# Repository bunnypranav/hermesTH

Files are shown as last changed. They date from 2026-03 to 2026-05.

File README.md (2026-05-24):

# Bunny's Hermes-TH
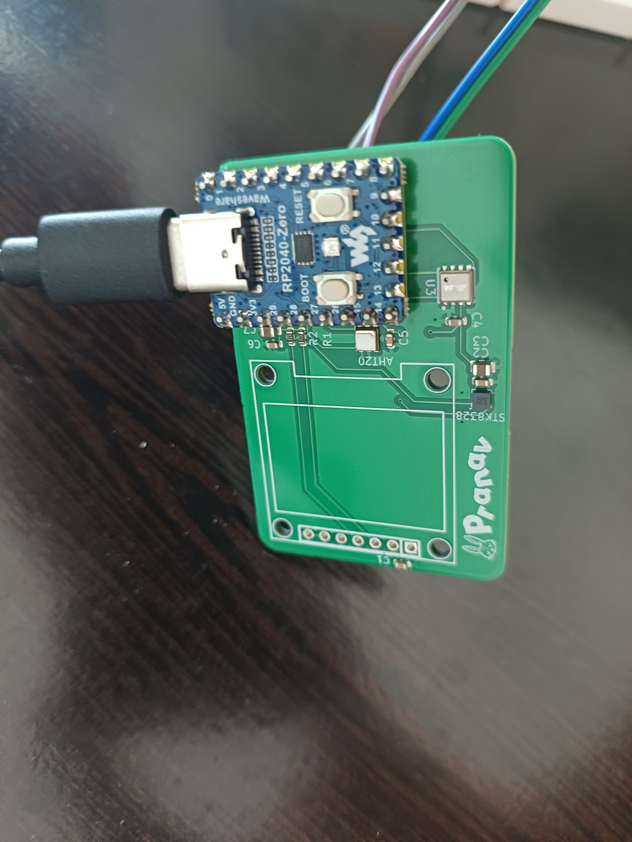
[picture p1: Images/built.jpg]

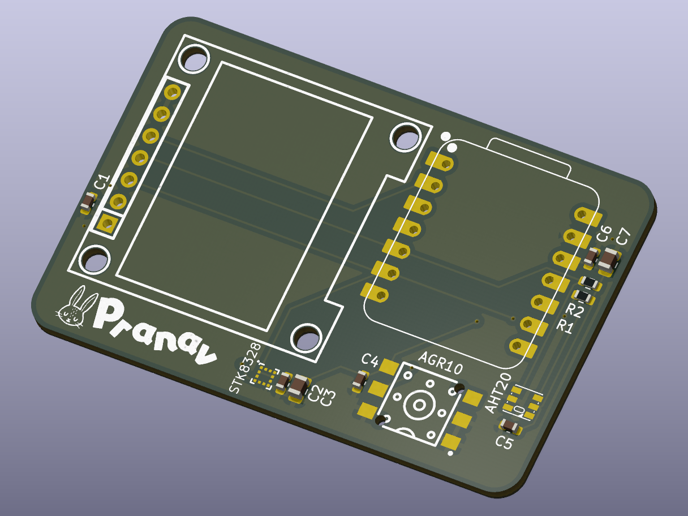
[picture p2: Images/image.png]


Hermes-TH is a small PCB that combines a temperature and humidity sensor, pressure sensor, and accelerometer, specifically the AHT20-F, AGR10, STK8328-C with a tiny OLED display, all controlled by a XIAO RP2040. The idea was to make a simple I2C-based board that reads environmental data that actually matters in my life, namely temperature, humidity, and pressure (unlike carbon monoxide for example), and displays it directly on a screen.

# Schematic
*Made in KiCad*

The XIAO RP2040 module handles everything. D4 and D5 are used for I2C (SCL and SDA), which are shared by the AHT20, OLED, and the accelerometer. The accelerometer is an analog device and read through the ADC pins of the RP2040, specifically A0. All other components are simply controlled through the I2C bus and everything is powered with 3.3V from the RP2040. The OLED is a 128x64 pixel display, which is more than enough for displaying all statistics.

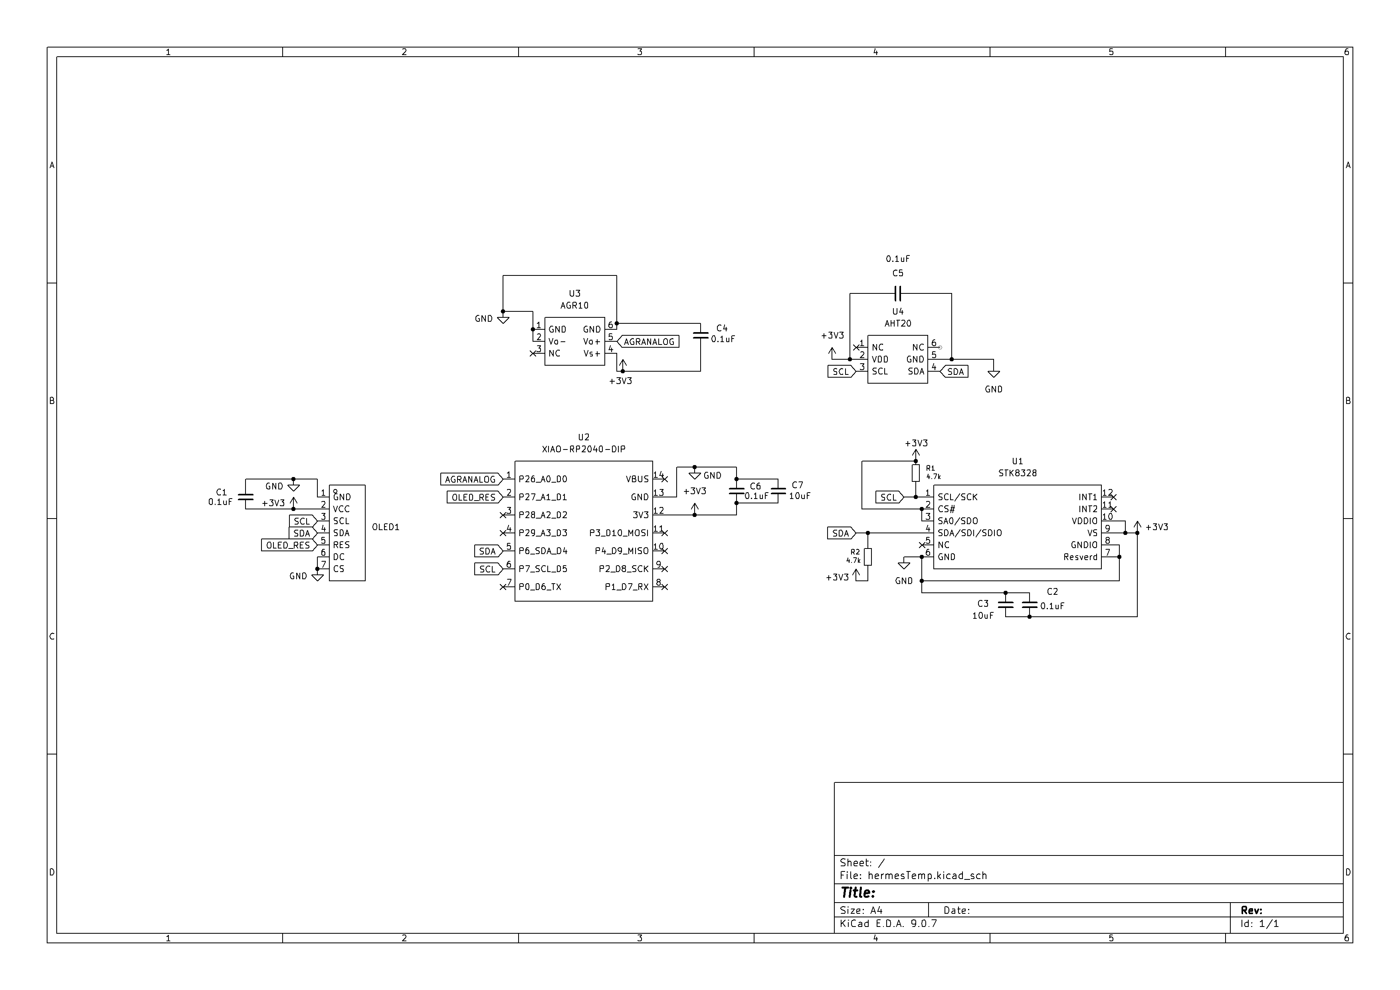
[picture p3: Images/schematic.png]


# PCB
*Made in KiCad*
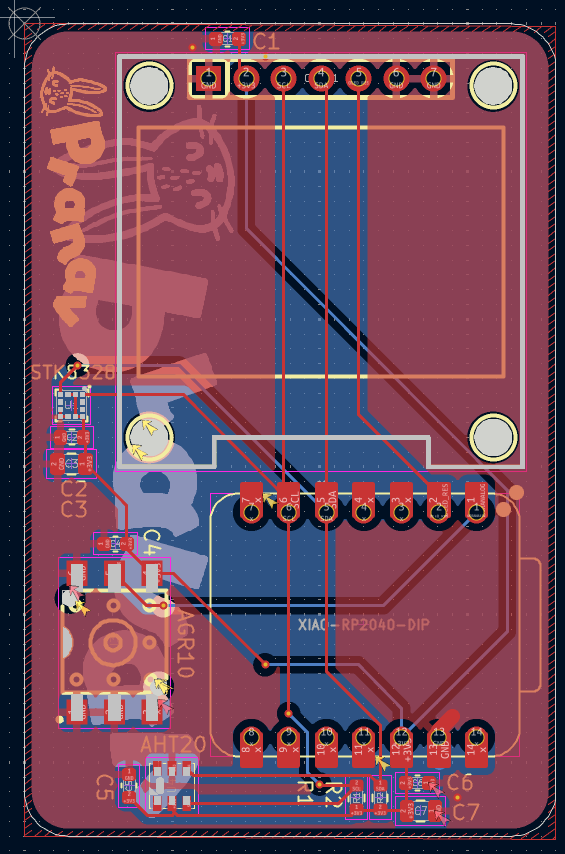
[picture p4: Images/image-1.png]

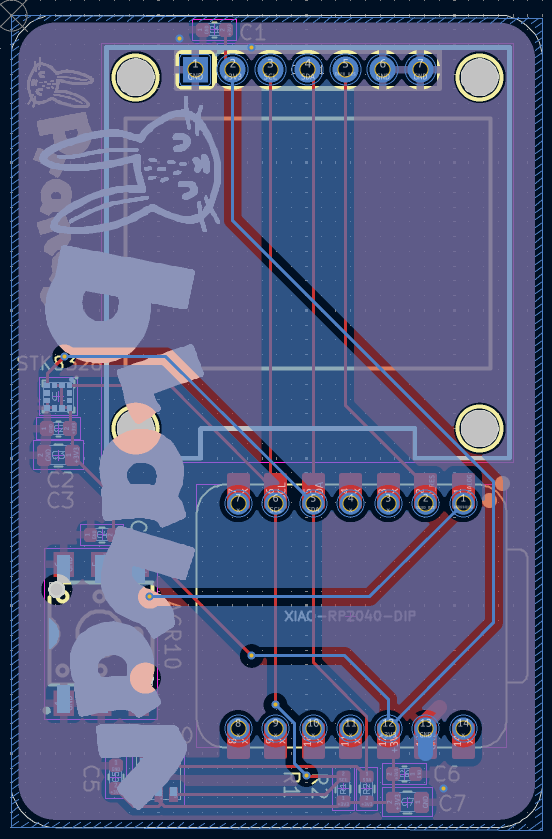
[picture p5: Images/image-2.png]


# BOM
* JLC PCBA: USD$37.5 (includes cost of some components)
* OLED: USD$1.9
* XIAO RP2040: USD$6.7
* Robu.in Shipping: USD$0.53
* **Total: USD$46.63**

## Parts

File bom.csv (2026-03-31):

Name | Purpose | Quantity | Total Cost (USD) | Link | Distributor
XIAO RP2040 | Main MCU | 1 | 6.70 | https://robu.in/product/seeed-studio-xiao-rp2040-v1-0/ | Robu
OLED Screen | Displaying the stats collected | 1 | 1.90 | https://robu.in/product/0-96-oled-display-module-spi-i2c-128x64-7-pin-blue/ | Robu
JLC PCB and Assemby | PCBA of SMD sensors, caps and resistors | 1 | 37.50 | https://jlcpcb.com/ | JLCPCB

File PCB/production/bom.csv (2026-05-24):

Designator | Footprint | Quantity | Value | LCSC Part #
C1, C2, C4, C5, C6 | 0603 | 5 | 0.1uF
C3, C7 | 0805 | 2 | 10uF
OLED1 | OLED-TH_HS96L01W4S03 | 1 | ~
R1, R2 | 0603 | 2 | 4.7k
U1 | VLGA-12_L2.0-W2.0-P0.50-BL | 1 | STK8328
U2 | MODULE_RP2040-ZERO | 1 | RP2040-ZERO
U3 | LGA-8_L3.8-W3.6-P0.90-TL_WF183D | 1 | ~
U4 | SENSOR-SMD-6_AHT20 | 1 | AHT20

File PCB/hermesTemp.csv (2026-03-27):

Reference | Qty | Value | DNP | Exclude from BOM | Exclude from Board | Footprint | Datasheet
C1,C2,C7 | 3 | 0.1uF |  |  |  | Capacitor_SMD:C_0603_1608Metric | ~
C3,C4,C5 | 3 | 1uF |  |  |  | Capacitor_SMD:C_0603_1608Metric | ~
C6,C9 | 2 | 4.7uF |  |  |  | Capacitor_SMD:C_0603_1608Metric | ~
C8 | 1 | 2.2uF |  |  |  | Capacitor_SMD:C_0603_1608Metric | ~
C10 | 1 | 10uF |  |  |  | Capacitor_SMD:C_0603_1608Metric | ~
R1,R2 | 2 | 4.7k |  |  |  | Resistor_SMD:R_0603_1608Metric | ~
R3 | 1 | 1M |  |  |  | Resistor_SMD:R_0603_1608Metric | ~
R4,R5 | 2 | 10k |  |  |  | Resistor_SMD:R_0603_1608Metric | ~
U1 | 1 | STM32F103C8T6 |  |  |  | hermesExtraFoot:STM32F103C8T6 | https://item.szlcsc.com/datasheet/LCKFB-DKX-STM32F103C8T6/24005615.html
U2 | 1 | AHT20-F |  |  |  | hermesExtraFoot:SENSOR-SMD-6_AHT20 | https://item.szlcsc.com/datasheet/AHT20-F/3517691.html
U3 | 1 | N069-9616TSWPG02-H14 |  |  |  | hermesExtraFoot:LCD-SMD_N069-9616TSWPG02-H14 | https://item.szlcsc.com/datasheet/N069-9616TSWPG02-H14/5717754.html

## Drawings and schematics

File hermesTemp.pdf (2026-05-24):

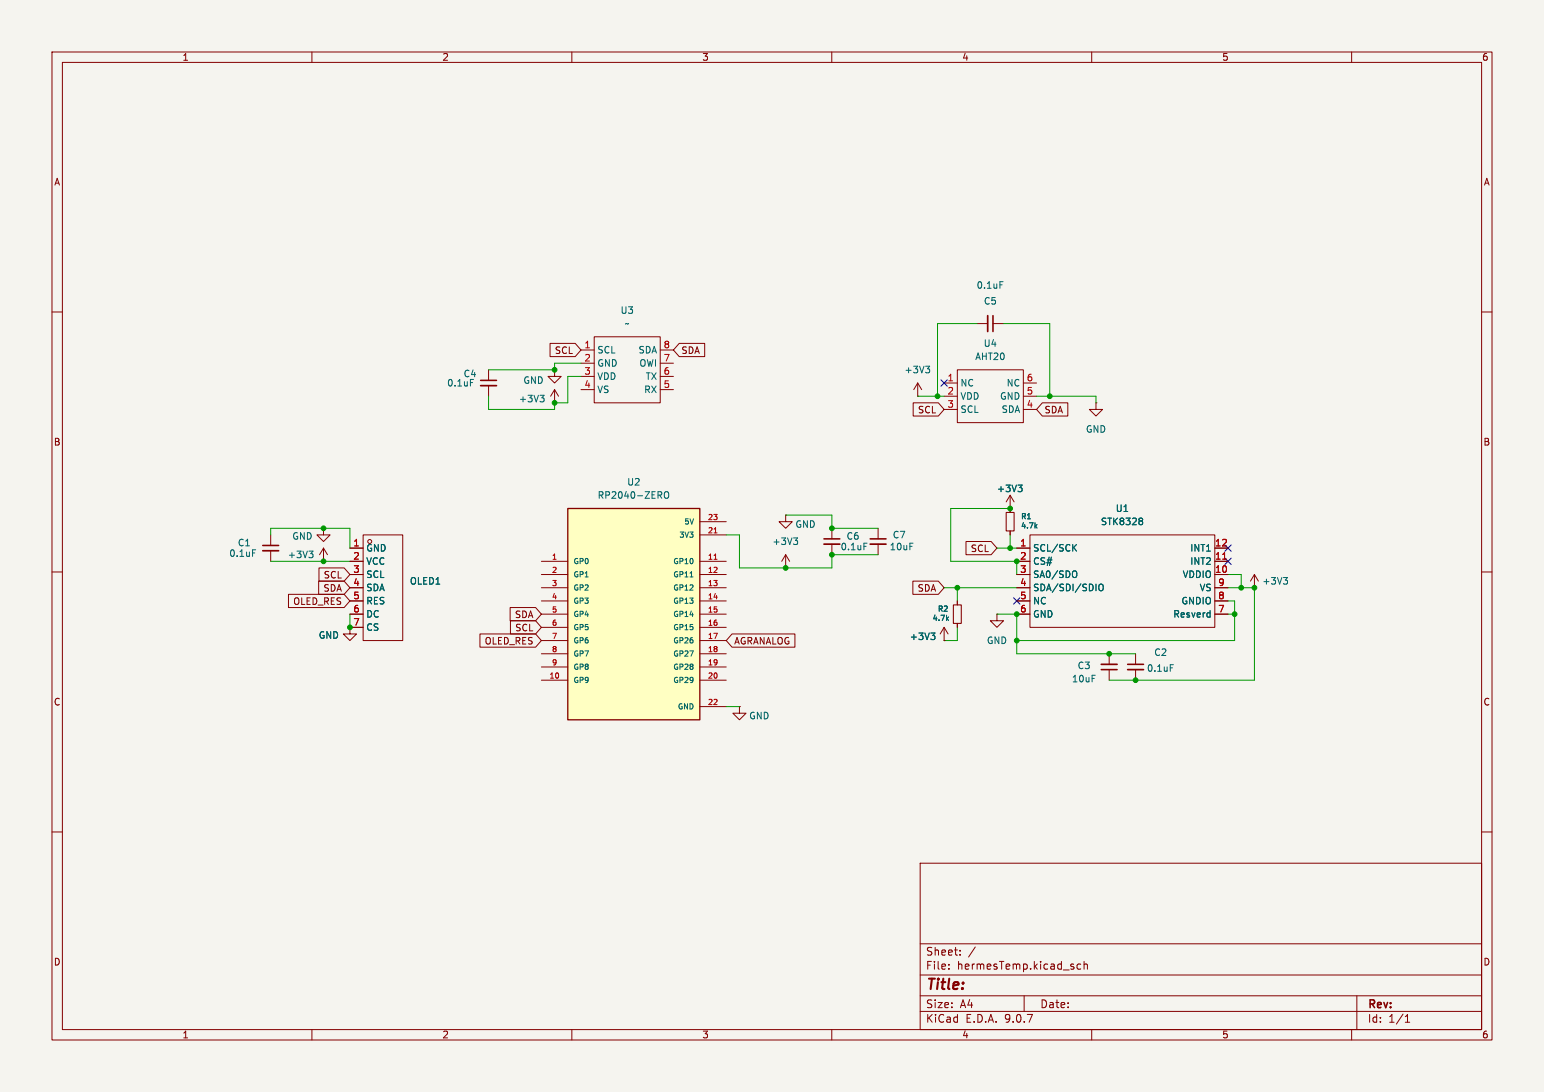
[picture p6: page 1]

Id: 1/1 Title: File: hermesTemp.kicad_sch Sheet: / C7

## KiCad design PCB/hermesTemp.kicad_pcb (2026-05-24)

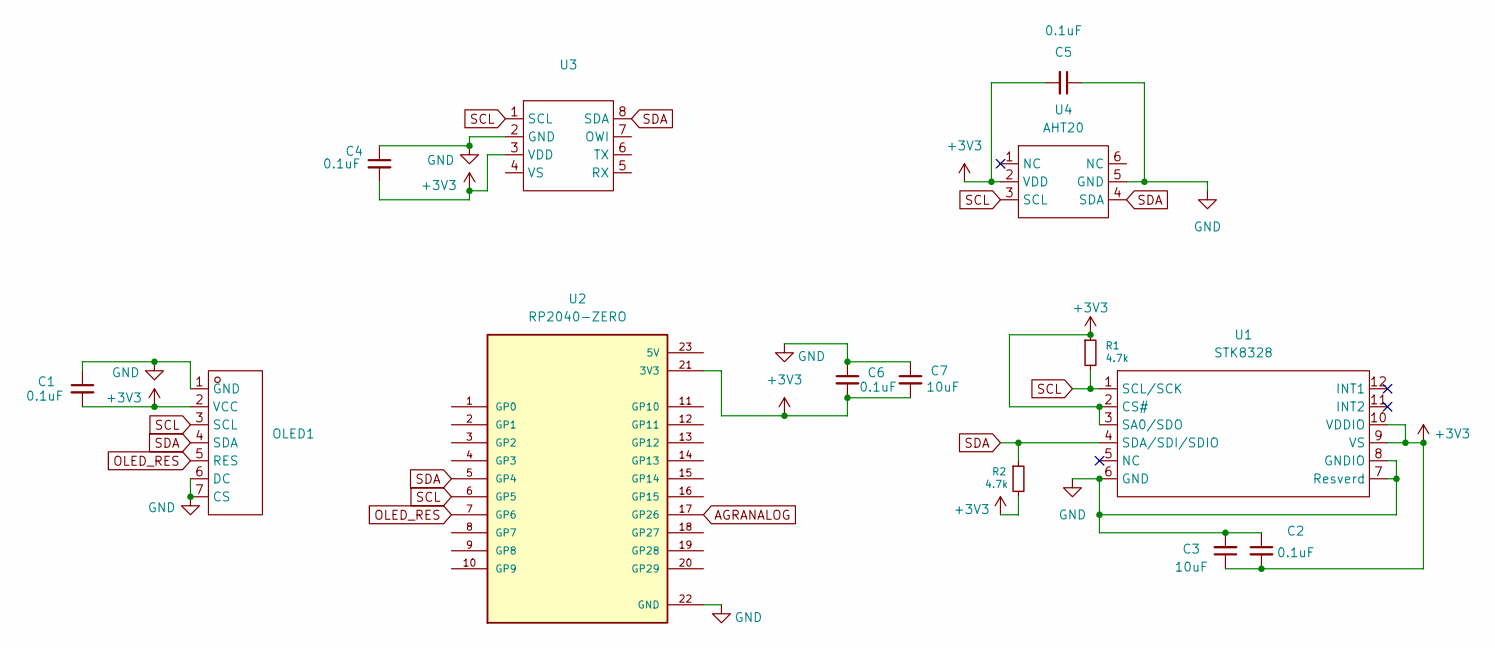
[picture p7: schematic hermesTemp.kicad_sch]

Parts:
C1, C2, C4, C5, C6: 0.1uF; C_0603_1608Metric
C3, C7: 10uF; C_0805_2012Metric
OLED1: OLED-TH_HS96L01W4S03; Manufacturer Part HS96L01W4S03; LCSC Part Name 0.96寸 白光 128x64像素分辨率
R1, R2: 4.7k; R_0603_1608Metric
U1: STK8328; VLGA-12_L2.0-W2.0-P0.50-BL; Manufacturer Part STK8328-C; LCSC Part Name 数字输出三轴MEMS加速度计
U2: RP2040-ZERO; MODULE_RP2040-ZERO; PARTREV NA
U3: LGA-8_L3.8-W3.6-P0.90-TL_WF183D; Manufacturer Part WF183DE 15BA L8N T&R; LCSC Part Name 数字压力传感器 量程：0-1500kpa 工作电压：2.4~5.5V 通信接口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
U4: AHT20; SENSOR-SMD-6_AHT20; Manufacturer Part AHT20-F; LCSC Part Name 温湿度传感器

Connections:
+3V3: C1.2, C2.2, C3.1, C4.2, C5.2, C6.2, C7.2, OLED1.2 (VCC), R1.1, R2.2, U1.2 (CS#), U1.3 (SA0/SDO), U1.9 (VS), U1.10 (VDDIO), U2.21 (3V3), U3.3 (VDD), U4.2 (VDD)
AGRANALOG: U2.17 (GP26)
GND: C1.1, C2.1, C3.2, C4.1, C5.1, C6.1, C7.1, OLED1.1 (GND), OLED1.6 (DC), OLED1.7 (CS), U1.6 (GND), U1.7 (Resverd), U1.8 (GNDIO), U2.22 (GND), U3.2 (GND), U4.5 (GND)
OLED_RES: OLED1.5 (RES), U2.7 (GP6)
SCL: OLED1.3 (SCL), R1.2, U1.1 (SCL/SCK), U2.6 (GP5), U3.1 (SCL), U4.3 (SCL)
SDA: OLED1.4 (SDA), R2.1, U1.4 (SDA/SDI/SDIO), U2.5 (GP4), U3.8 (SDA), U4.4 (SDA)

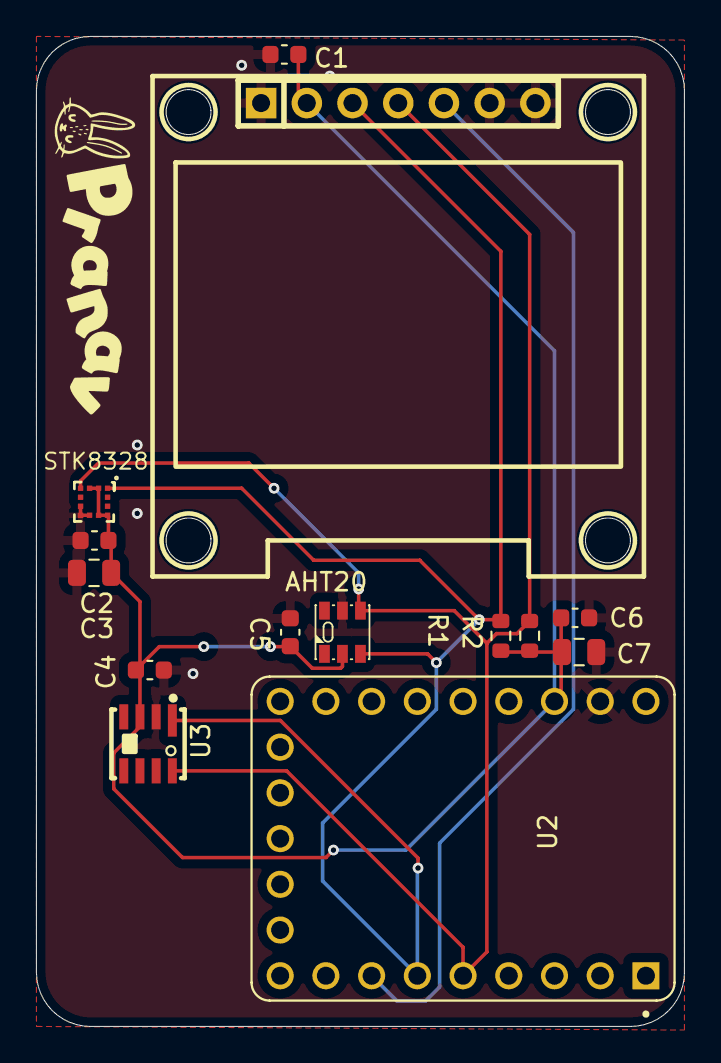
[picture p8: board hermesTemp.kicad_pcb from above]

Board: 2 copper layers, 36.0 x 55.0 mm, 15 parts (1 on the bottom side), 5 nets.

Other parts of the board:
P2: LOGO

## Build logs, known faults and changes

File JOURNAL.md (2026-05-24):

<!--
  This journal is auto generated by Stasis.
-->

# 5/24/2026 10 AM - Build done!

_Time spent: 1.25h_

Finally finished the build of the project! The screen correctly displays the values from the sensors, and regularly updates them. 

I have to say, it wasn't without any struggles. Biggest problem was that the screen that I put in the PCB uses SPI, but I wired it up for I2C. Tiny misprints making our lives harder, *sigh!* So now the only way I had was to use another I2C screen I had lying around, and connect it to the breadboard. Changing or ordering another PCB is of no use, I don't have the US$40-ish to pay to JLC along with another US$10 for customs. Anyways, this was a hobby prototype, and it works perfectly relative to prototypes. Enjoy the photos!

built1

built2




# 3/31/2026 4 PM - Rework design based on review feedback

_Time spent: 4.5h_

This update mostly happened because of the feedback I got on the last review. The main issue was that the project wasn't complex for Tier 2, and was too expensive for Tier 1. Additionally, the reviewer pointed out some key cost-cutting measures, which I did feel were really doable. So I had to rethink the direction a bit instead of just tweaking small things.

Earlier, it was mostly just a display and one sensor. Based on the suggestion, I added two more sensors;  the STK8328 accelerometer, and the AGR10 pressure sensor. It also made me deal with two types of interfaces, namely I2C and analog, which added to the complexity in a meaningful way.



Another suggestion was about my PCBA choice and improving how parts were sourced. I made the OLED setup simpler by using a module instead of bare SMD ribbon cable, which got me rid of the complex charge pump system and related.  The feedback about the STM32 and PCBA cost also made me rethink the microcontroller choice. I switched to the XIAO RP2040, sourced through Robu and will be later soldered by me. Not getting the OLED and MCU through PCBA will reduce the cost, since PCBA will buy and solder two of each component, something that is not cost-effective at all.



I also updated the firmware to work with all the new components, and it now used CircuitPython. The pressure part is a bit rough since it's based on a simple and uncalibrated conversion for now.



Overall, I think I addressed the feedback properly. The project is now clearly more complex than before, while also being more practical and cheaper to build, relative to the components used.





# 3/25/2026 11 AM - PCB Routing and firmware

_Time spent: 3.25h_

PCB routing was actually pretty easy. There were only 3 main components, the MCU (STM32), the OLED display, and the AHT20. The rest are pull up resistors, and a whole array of decoupling capacitors. Since this is not my very first time using them, I am aware that they should be placed as close as possible to the pins. Fortunately, I am getting this as a PCBA, so size is not a problem. I went with 0605 size, so I could fit them all fairly easily around the pins. A dual ground plane helped for routing, noise, as well as aesthetics.  Regarding the firmware, I just wanted a proof of concept, since this is my first time using an STM32, and therfore I know next to nothing about it. Using my basic knowledge of MicroPython, and some help from an AI, I created the most basic firmware. This is subject to most amount of change, for afformentioned reasons. Adding some ~~propoganda~~ branding of my own, and the PCB routing along with the full design is finally done!

Cherish some PCB images below, thanks for taking a look at my design!












# 3/25/2026 8 AM - Schematic

_Time spent: 2.5h_

After less time than I expected, but more components than I expected, I have finished the schematic! I thought it would just be connecting components together, but there were a lot of small details.

The STM32 module itself was straightforward since most pins were already labelled clearly; although my first time needing pull up resistors, cause I previously only worked with Picos (they have this in-built). The AHT20 sensor was also relatively simple.

The OLED display was the behemoth of confusion. It had a lot extra pins that I didn't understand, especially the "charge pump" ones: C1P, C1N, C2P, and C2N. I had to refer to the datasheet multiple times (and other sources to look up sample wiring) and still wasn't fully confident about whether I understood everything correctly. Adding the numerous required capacitors and the resistor made the schematic look even more complicated.

The decoupling capacitors were also frustrating to draw up. Every component seemed to need more than one! I ended up following general guidelines, like adding a mix of small and big ones.

I had to go through this big mess multiple times, checking connections and making sure nothing was left; eventually everything seemed to be connected properly.














# 3/24/2026 12 PM - Researching parts and finalizing BOM

_Time spent: 3h_

At the start of this project, I wanted to use the bare RP2040 SMD version. It is used in a lot of projects and I was fairly familiar with RPI Picos. Once I actually started researching how to use the bare chip though, I realised that it needed a lot of extra components like flash memory, crystal oscillator, power stuff, and a bunch of capacitors. This was beyond the Hermes' simple I2C board.

Therefore, I switched to the STM32 module (STM32F103C8T6, specifically, since that is available in JLC PCB fab). For the sensor, I chose the AHT20 because it was popular and cheap. The OLED display choice was a lot more confusing. I wanted this to be a fully assembled PCB, since that is cheaper than ordering components from local sellers. So I deeply searched through JLC's parts library, keeping in mind economic PCBA and trying my best to avoid exteneded components to save on cost. That particulary was a very big problem for the OLED, since it had too many variables like having I2C, being eligible for economic PCBA, and not having assembly difficulty of "high" (this was a new one for me, but very important cause each such component adds more than 3 USD to it's assembly). I also had to add a whole array of decoupling caps and resistors for making these work, something I will ellaborate in the next journal.

I finally settled on these for my main components:
https://jlcpcb.com/partdetail/Aosong_Guangzhou_Elec-AHT20F/C3012622
https://jlcpcb.com/partdetail/Newvisio-N069_9616TSWPG02H14/C5123561
https://jlcpcb.com/partdetail/LCSCboards-LCKFB_DKXSTM32F103C8T6/C22396880











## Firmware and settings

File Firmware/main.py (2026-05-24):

import time
import struct
import framebuf
from machine import I2C, Pin

i2c = I2C(0, sda=Pin(4), scl=Pin(5), freq=400_000)


def i2c_write(addr, data):
    i2c.writeto(addr, data)


def i2c_read(addr, n):
    return i2c.readfrom(addr, n)


def i2c_write_reg(addr, reg, val):
    i2c.writeto(addr, bytes([reg, val]))


def i2c_read_reg(addr, reg, n):
    i2c.writeto(addr, bytes([reg]))
    return i2c.readfrom(addr, n)


# STK8328-C
STK_ADDR = 0x1F
STK_REG_CHIP_ID = 0x00
STK_REG_XOUT1 = 0x02
STK_REG_RANGESEL = 0x0F
STK_REG_BWSEL = 0x10
STK_REG_POWMODE = 0x11
STK_REG_SWRST = 0x14

STK_RANGE_2G = 0x03
STK_RANGE_4G = 0x05
STK_RANGE_8G = 0x08
STK_RANGE_16G = 0x0C
STK_BW_125HZ = 0x0C

_STK_SENSITIVITY = {
    STK_RANGE_2G: 16384.0,
    STK_RANGE_4G: 8192.0,
    STK_RANGE_8G: 4096.0,
    STK_RANGE_16G: 2048.0,
}
_stk_range = STK_RANGE_8G


def stk_init():
    i2c_write_reg(STK_ADDR, STK_REG_SWRST, 0xB6)
    time.sleep_ms(10)
    chip_id = i2c_read_reg(STK_ADDR, STK_REG_CHIP_ID, 1)[0]
    if chip_id != 0x25:
        print("[STK8328] WARNING: chip_id 0x{:02X} (expected 0x25)".format(chip_id))
    else:
        print("[STK8328] chip_id OK: 0x{:02X}".format(chip_id))
    i2c_write_reg(STK_ADDR, STK_REG_POWMODE, 0x80)
    time.sleep_ms(2)
    i2c_write_reg(STK_ADDR, STK_REG_RANGESEL, _stk_range)
    i2c_write_reg(STK_ADDR, STK_REG_BWSEL, STK_BW_125HZ)
    i2c_write_reg(STK_ADDR, STK_REG_POWMODE, 0x00)
    time.sleep_ms(5)


def stk_read_accel():
    raw = i2c_read_reg(STK_ADDR, STK_REG_XOUT1, 6)

    def s16(lo, hi):
        v = (hi << 8) | lo
        return v - 0x10000 if v >= 0x8000 else v

    sens = _STK_SENSITIVITY[_stk_range]
    return (
        s16(raw[0], raw[1]) / sens,
        s16(raw[2], raw[3]) / sens,
        s16(raw[4], raw[5]) / sens,
    )


# WF183DE
WF_ADDR = 0x6D
WF_REG_CMD = 0x0A
WF_REG_PRES = 0x0B
WF_REG_TEMP = 0x0F
WF_REG_STS = 0x13
WF_CMD_TEMP = 0x04
WF_CMD_PRES = 0x06


def _wf_wait(timeout_ms=200):
    t = time.ticks_add(time.ticks_ms(), timeout_ms)
    while time.ticks_diff(t, time.ticks_ms()) > 0:
        try:
            i2c.writeto(WF_ADDR, bytes([WF_REG_STS]))
            if i2c.readfrom(WF_ADDR, 1)[0] & 0x01:
                return True
        except Exception:
            pass
        time.sleep_ms(5)
    return False


def wf_read_temp():
    i2c.writeto(WF_ADDR, bytes([WF_REG_CMD, WF_CMD_TEMP]))
    _wf_wait()
    i2c.writeto(WF_ADDR, bytes([WF_REG_TEMP]))
    raw = i2c.readfrom(WF_ADDR, 2)
    val = (raw[0] << 8) | raw[1]
    if val >= 0x8000:
        val -= 0x10000
    return val / 10.0


def wf_read_pressure():
    i2c.writeto(WF_ADDR, bytes([WF_REG_CMD, WF_CMD_PRES]))
    _wf_wait()
    i2c.writeto(WF_ADDR, bytes([WF_REG_PRES]))
    raw = i2c.readfrom(WF_ADDR, 4)
    val = (raw[0] << 24) | (raw[1] << 16) | (raw[2] << 8) | raw[3]
    return val / 1000.0


# OLED
OLED_ADDR = 0x3C
OLED_W = 128
OLED_H = 64

_OLED_INIT_CMDS = bytes(
    [
        0xAE,
        0xD5,
        0x80,
        0xA8,
        0x3F,
        0xD3,
        0x00,
        0x40,
        0x8D,
        0x14,
        0x20,
        0x00,
        0xA1,
        0xC8,
        0xDA,
        0x12,
        0x81,
        0xCF,
        0xD9,
        0xF1,
        0xDB,
        0x40,
        0xA4,
        0xA6,
        0xAF,
    ]
)

_oled_buf = bytearray(OLED_W * OLED_H // 8)
_oled_fb = framebuf.FrameBuffer(_oled_buf, OLED_W, OLED_H, framebuf.MONO_VLSB)
_oled_present = False


def _oled_cmds(data):
    for b in data:
        i2c.writeto(OLED_ADDR, bytes([0x00, b]))


def oled_init():
    global _oled_present

    if OLED_ADDR not in i2c.scan():
        print("[OLED]   not found on bus (0x{:02X})".format(OLED_ADDR))
        return False
    try:
        _oled_cmds(_OLED_INIT_CMDS)
        _oled_fb.fill(0)
        oled_show()
        _oled_present = True
        print("[OLED]   initialised (128x64, 4-pin no reset)")
        return True
    except Exception as e:
        print("[OLED]   init error:", e)
        return False


def oled_show():
    if not _oled_present:
        return
    _oled_cmds(bytes([0x21, 0, 127, 0x22, 0, 7]))
    chunk = 16
    for offset in range(0, len(_oled_buf), chunk):
        i2c.writeto(OLED_ADDR, b"\x40" + _oled_buf[offset : offset + chunk])


def oled_update(ax, ay, az, t_wf, pres):
    fb = _oled_fb
    fb.fill(0)

    fb.fill_rect(0, 0, 128, 12, 1)
    fb.text("HERMES SENSORS", 8, 2, 0)

    fb.text("STK8328", 4, 16, 1)
    fb.text("X: {:.2f} g".format(ax if ax is not None else 0), 4, 28, 1)
    fb.text("Y: {:.2f} g".format(ay if ay is not None else 0), 4, 40, 1)
    fb.text("Z: {:.2f} g".format(az if az is not None else 0), 4, 52, 1)
    fb.vline(82, 16, 48, 1)
    fb.text("WF183", 88, 16, 1)

    if t_wf is not None:
        fb.text("{:.1f}C".format(t_wf), 88, 32, 1)
    else:
        fb.text("T:N/A", 88, 32, 1)

    if pres is not None:
        fb.text("{:.1f}".format(pres), 88, 44, 1)
        fb.text("kPa", 88, 54, 1)
    else:
        fb.text("P:N/A", 88, 44, 1)

    oled_show()


# Main


def scan_bus():
    devices = i2c.scan()
    print("I2C scan:", [hex(d) for d in devices])


def main():
    print("=" * 50)
    print("  Hermes Sensor Board - MicroPython")
    print("=" * 50)

    time.sleep_ms(200)
    scan_bus()

    print("\nInitialising sensors...")
    stk_init()
    print("[WF183DE] ready")
    oled_init()

    print("\nStarting read loop. Press Ctrl-C to stop.\n")
    print(
        "{:>8} | {:>7} {:>7} {:>7} | {:>11} {:>9} | {:>10} {:>10}".format(
            "Time(s)", "Ax(g)", "Ay(g)", "Az(g)", "Temp_WF", "Pres(kPa)"
        )
    )
    print("-" * 85)

    t0 = time.ticks_ms()

    def fmt(v, w, d):
        return (
            "{:>{}.{}f}".format(v, w, d)
            if v is not None
            else "{:>{}s}".format("N/A", w)
        )

    while True:
        elapsed = time.ticks_diff(time.ticks_ms(), t0) / 1000.0

        try:
            ax, ay, az = stk_read_accel()
        except Exception as e:
            ax = ay = az = None
            print("[STK8328] read error:", e)

        try:
            t_wf = wf_read_temp()
            pres = wf_read_pressure()
        except Exception as e:
            t_wf = pres = None
            print("[WF183DE] read error:", e)

        print(
            "{:>8.1f} | {} {} {} | {} {} | {} {}".format(
                elapsed,
                fmt(ax, 7, 3),
                fmt(ay, 7, 3),
                fmt(az, 7, 3),
                fmt(t_wf, 10, 1),
                fmt(pres, 10, 3),
            )
        )

        # OLED update (Passing STK and WF stats)
        if _oled_present:
            try:
                oled_update(ax, ay, az, t_wf, pres)
            except Exception as e:
                print("[OLED]   display error:", e)

        time.sleep_ms(1000)


if __name__ == "__main__":
    main()

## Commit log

2026-03-31 Update based on reviewer feedback.
    Switched to XIAO RP2040 (dropped STM32 + PCBA for MCU/OLED) to simplify design and reduce cost. Increased project complexity by adding STK8328 accelerometer and AGR10 pressure sensor alongside AHT20.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
    [bom.csv, designators.csv, hermesTemp.kicad_pcb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]
2026-05-24 Build review update
    [bom.csv, freerouting.dsn, hermesTemp.kicad_pcb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]
